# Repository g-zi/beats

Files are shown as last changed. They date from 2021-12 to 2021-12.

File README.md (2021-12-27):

# BEATS
## Beat Couter, MIDI controller and DMX light controller in one

A small box that is connected to the computer via USB and shows the beat as a clock and digits so that can be mixed in the beat. It can be used as a MIDI and DMX controller and can control a lighting system in the beat.

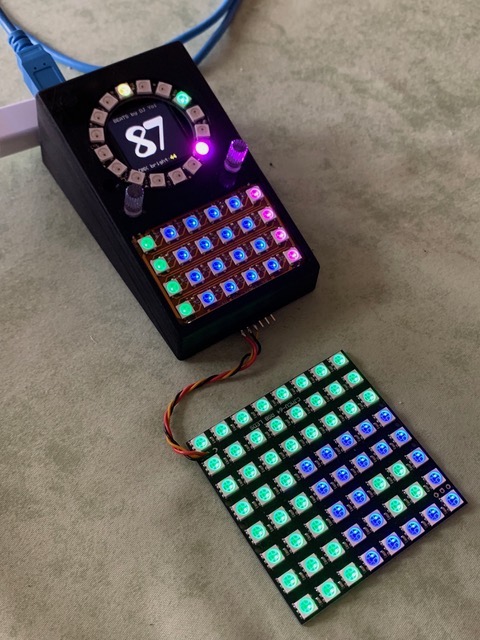
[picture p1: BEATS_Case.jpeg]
BEATS Case

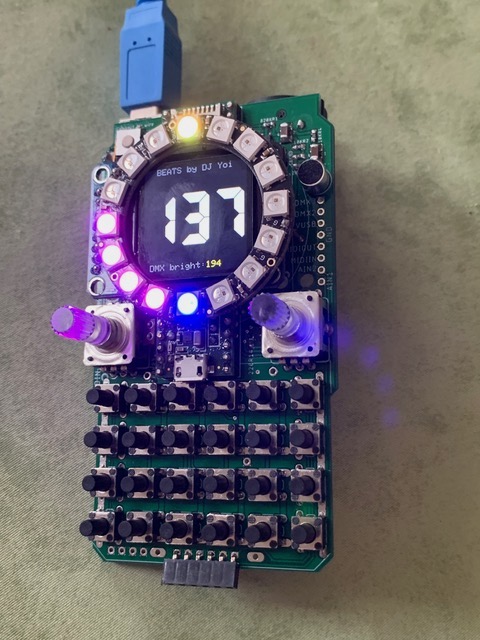
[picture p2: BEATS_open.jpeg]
BEATS open
 

The Beat Counter knows 3 operating modes:

- MIDI (drum pad, beat clock and metronome)
- Scanners (and moving heads with up to 8 scanners with 8 channels or 4 scanners with up to 16 channels)
- COB (Pixbar and Pattern)

Can operate with anything that sends/receives MIDI commands: Ableton Live, Serato, Traktor …

Beat length adjustable, inclined beats such as 9 are also adjustable.
The key matrix is pressure-sensitive and illuminated with RGB LEDs. A milky silicone pad is attached to the key matrix.
There are two illuminated encoders that are used to set the lighting system and can also send MIDI signals.
Reads and writes MIDI signals via USB and DIN socket.
Outputs DMX control signals for light control for COB bars, 8x8 COB arrays and scanners / moving heads. Up to 8 scanners / moving heads can be controlled at the same time.
SD card slot accessible from the rear.
The housing is designed with OpenSCAD and is printed with 3D printers (Form3 or FDM)
The current version uses a Teensy 3.6, the next version will have a Teensy 4.1 (600Mhz).
The board is two-sided and created with Eagle.

Here some videos: 
- Controlling scanners / moving heads: https://www.youtube.com/watch?v=9kyjajE7mRk
- Animation of the circuit board: https://www.youtube.com/watch?v=K_6d6vQXQpI 
- Inner workings with a few functions: https://www.youtube.com/watch?v=Ms0J2bLOR1w 
- 4 x Showtec Pixel Square 16 COB (old version): https://www.youtube.com/watch?v=BX3hZSje4Ws
- Also works with bars (old version): https://www.youtube.com/watch?v=ibh8aw3B2aw
- MIDI Beat Counter Setup and Menues Part 1: https://www.youtube.com/watch?v=dCm0thBqy6s
- MIDI Beat Counter Setup and Menues Part 2: https://www.youtube.com/watch?v=OodJnmjo3fk

In MIDI mode, the key matrix is used as pressure-sensitive pads for e.g. Ableton Live. All buttons send MIDI commands. The two encoders send MIDI commands for buttons and each can be switched between 3 settings. MIDI channel and address can be set.

The scanner mode is used to control up to 8 scanners or moving heads with 8 channels or 4 scanners with up to 16 channels. All settings such as pan, tilt, color, strobe etc. can be set individually for each scanner and up to 32 settings can be saved by now.

In movement mode there are 9 movement patterns such as Left-Right, Circle, Swing etc. which the scanner let move to the rhythm of the music. The movement path and speed can be selected, in beat in steps and free run mode.

The COB mode is for COB-LED walls, until now for a matrix of 8x8 COBs. A counting pattern can be set or programmed patterns can be send out. The patterns run to the beat of the music, foreground and background brightness can be adjusted. Lightbulbs are simulated, slowly decay.

The housing is designed to be as stable as possible. On the underside there are bars under the key matrix so that nothing can bend or break even with firm pressure. The two screws for the circuit board are in the immediate vicinity of the encoder, even here nothing can be broken by applying too much pressure to the encoder. An M8 nut will also be integrated into the housing on the underside so that the device can also be screwed on. The size of the Beat Counter is kept compact and can therefore be mounted within sight.

## Further development:

The USB host port can be used to connect external devices, keyboard, drum pads etc. (Korg, Akai) https://www.pjrc.com/wp-content/uploads/2020/05/teensy41_usbhost3.jpg https://forum.pjrc.com/teensy41_usbhost2.jpg

Explanation to DMX: https://en.wikipedia.org/wiki/DMX512#RJ-45_pinout

In the current device I am using a Teensy 3.6. I am developing a circuit board for the Teensy 4.1. Teensy 4.1: https://www.pjrc.com/store/teensy41.html

Instead of the MIDI-DIN socket, an RJ45 socket will be installed: Ethernet can be used to beat-link CDJs such as beat-link-trigger or for Art-Net

Art-Net: https://artisticlicence.com/WebSiteMaster/User%20Guides/art-net.pdf

Conversion of the pattern for the COB-LED walls to the SD card and writing the program for generating the pattern, then larger output than 8x8 are possible.

Teensy 4.1 can use S/PDIF and can be later used for sound analysis, Fourier transformation and as an effects device: https://en.wikipedia.org/wiki/S/PDIF

The displays are also available in round. This display can be exchanged 1: 1 (same driver ST7789): 250nits: http://www.panelook.com/TVT0128A-I-IPS-1-28-Inch-240x240-Round-TFT-LCD-Circular-Display-Module-For-VR-detail_71679.html 400nits: http://www.panelook.com/TVT0128C-I-IPS-1-28-Inch-240x240-Round-TFT-LCD-Circular-Display-Module-For-VR-detail_98507.html or as OLED with 400x400 resolution, but are quite expensive and probably too slow: https://www.ebay.de/itm/Real-AMOLED-Display-1-39-inch-400-400-Round-Circle-Circular-OLED-LCD-Module/192716558403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

An LED strip control can also be installed, the neopixels are already controlled like this: https://www.ebay.de/itm/WS2812B-LED-Streifen-Strip-5M-WS2812-RGB-Leiste-Licht-5050-SMD-Adressbaren-DC5V/222192610445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Ⓜ️m48DHbcLw8Ppkncw-fkDSGA

Something else interesting could easily be integrated: https://github.com/saikoLED/TeensyLED

If someone is interrested to build it, I still have some PCB's and can send for 10 Euros each plus shipping costs. For further questions send email to g.zi@gmx.de

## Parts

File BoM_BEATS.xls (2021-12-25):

Teensy Beat Counter |  | Bill of Material
Amount | Part | Value | Device | Package | Seller | Seller N° | Price € | Total | Remark
1 | Teensy | 3.6 | Teensy 3.6 | Teensy_3.6 | exp-tech.de | EXP-R05-965 | 30.39 | 30.39
1 | NEO16RING | 16 | Neopixel Ring 16 | Neo16ring3 | exp-tech.de | EXP-R15-225 | 10.65 | 10.65 | Reichelt: DEBO LED NP16
1 | WS_1.3"240X240 | 1.3" 240X240 | WS_1.3"240X240 | WS_1.3"240X240 | exp-tech.de | EXP-R63-227 | 10.06 | 10.06
1 | FSR | 44x44mm | interlink 406 | 44x44mm | exp-tech.de | EXP-R15-074 | 10.65 | 10.65
3 | NeoPixel RGB | RGB-LED | NeoPixel RGB LED | 5050 | exp-tech.de | EXP-R15-315 | 2.38 | 7.14 | 10 Pack
2 | RGB Encoder | ENC1 & ENC2 | RGB Encoder | ENCODER_LED_3_LONG | ebay.de albs-alltronic (http://www.reichelt.de/) | 1x/10x Encoder RGB LED | 4.00 | 8.00
1 | DMX | NC3FAH2 | NC3FAH2 | NC3FAH2 | thomann.de | Neutrik NC3 FAH1 | 1.09 | 1.09
1 | MIC | F6035AP | F6035AP | F6035AP | reichelt.de | EMY-63M/P | 0.95 | 0.95
1 | USB-B | USB-B-H | USB-B-H | USB-B-H | reichelt.de | RND 205-00858 | 0.25 | 0.25
1 | MAX3468 | MAX3468CSA | MAX3468CSA | SO08 | reichelt.de | SP 485 CNL | 0.77 | 0.77
2 | OPA344 | MCP6401 | LM 8261 | SOT23-5 | reichelt.de | MCP 6401T-E/OT | 0.30 | 0.60 | LM 8261 M5 | OPA 335 AIDBVT
3 | 4.7µF C1-C3 | 4.7µF | C-EUC1210 | C1210 | reichelt.de | X7R-G1206 4,7/50 | 0.20 | 0.60
16 | 220R R1-R16 | 220R | R-EU_R0603 | R0603 | reichelt.de | SMD-0603 220 | 0.03 | 0.48
1 | 2K2R1 | 2K2 | R-EU_R0603 | R0603 | reichelt.de | SMD-0603 2,2K | 0.03 | 0.03
6 | 10K R1-R6 | 10K | R-EU_R0603 | R0603 | reichelt.de | SMD-0603 10K | 0.03 | 0.18
3 | 100K R1-R3 | 100k | R-EU_R0603 | R0603 | reichelt.de | SMD-0603 100K | 0.03 | 0.09
1 | 820KR1 | 820K | R-EU_R0603 | R0603 | reichelt.de | SMD-0603 820K | 0.10 | 0.10
1 | Button | SMD_5.2MM | SMD_5.2MM | SMD_5.2MM | reichelt.de | OMR B3FS-1002P | 0.21 | 0.21
24 | Switch | 9.5mm | B3F-10XX | B3F-10XX | reichelt.de | TASTER 3301B | 0.15 | 3.60
1 | Buchsenleiste | 20 pol | Buchsenleiste | Buchsenleiste | reichelt.de | BL 1X20W 2,54 | 0.80 | 0.80
1 | Schraube | M3 x 18mm | Schraube | Senkkopf | minischrauben.com | 10642-2-318 | 5.01 | 0.05 | https://minischrauben.com/senkschrauben-m-3-x-18-ve100--30680.html
1 | Schraube | M3 x 15mm | Schraube | Zylinderkopf | minischrauben.com | 912-2-314 | 3.27 | 0.03 | https://minischrauben.com/zylinderschrauben-m-3-x-14-ve100--13029.html
2 | Schraube | M2 x 12mm | Schraube | Torx | minischrauben.com | 965tx-2-212-50 | 2.12 | 0.0848 | https://minischrauben.com/senkschrauben-m-2-x-12-ve50--36215.html
2 | Schraube | M2 x 20mm | Schraube | Torx | minischrauben.com | 965tx-2-220-50 | 2.12 | 0.0848 | https://minischrauben.com/senkschrauben-m-2-x-20-ve50--36217.html
2 | Schraube | M3 x 10mm | Schraube | Torx | minischrauben.com | 965tx-2-38-50 | 2.03 | 0.0812 | https://minischrauben.com/senkschrauben-m-3-x-8-kp--50-stueck--42896.html
1 | Mutter | M3 | Mutter | M3 | minischrauben.com | 934-4-2-100 | 2.45 | 0.098 | https://minischrauben.com/sechskantmuttern-m-2-ve100--1997.html
2 | Beilagscheibe | M3 Isolierend | Beilagscheibe | M3 | pegnitz-schrauben.de | 9021903 | 0.05 | 0.10 | https://www.pegnitz-schrauben.de/U-Scheiben-DIN-9021-Polyamid-32mm-fuer-M3 | https://www.ebay.de/itm/222409316877
1 | Foil | 55x37mm | Foil | Foil | DJ_Yoi | MBC 3.6 Foil | 1.00 | 1.00
1 | 6x4 PCB | 6x4 PCB | 6x4 PCB | 6x4 PCB | DJ_Yoi | MBC 3.6 6x4 PCB | 10.00 | 10.00
1 | PCB | PCB | PCB | PCB | DJ_Yoi | MBC 3.6 PCB | 10.00 | 10.00
1 | Case | Case | Case | Case | DJ_Yoi | MBC 3.6 Case | 10.00 | 10.00
 |  |  |  |  |  |  |  | 118.17 | €

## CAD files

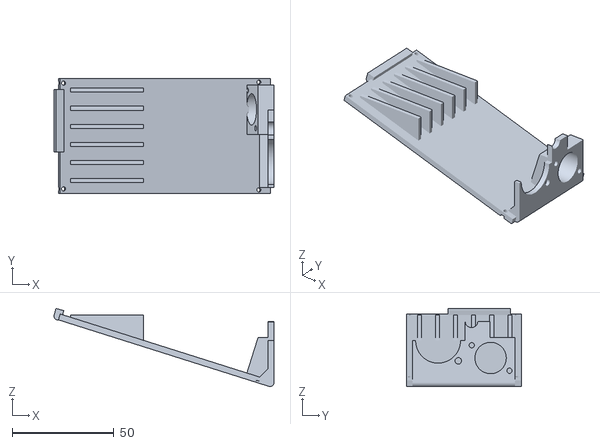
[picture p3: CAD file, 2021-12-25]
BEATS_bottom.stl
107.9 x 56.2 x 38.3

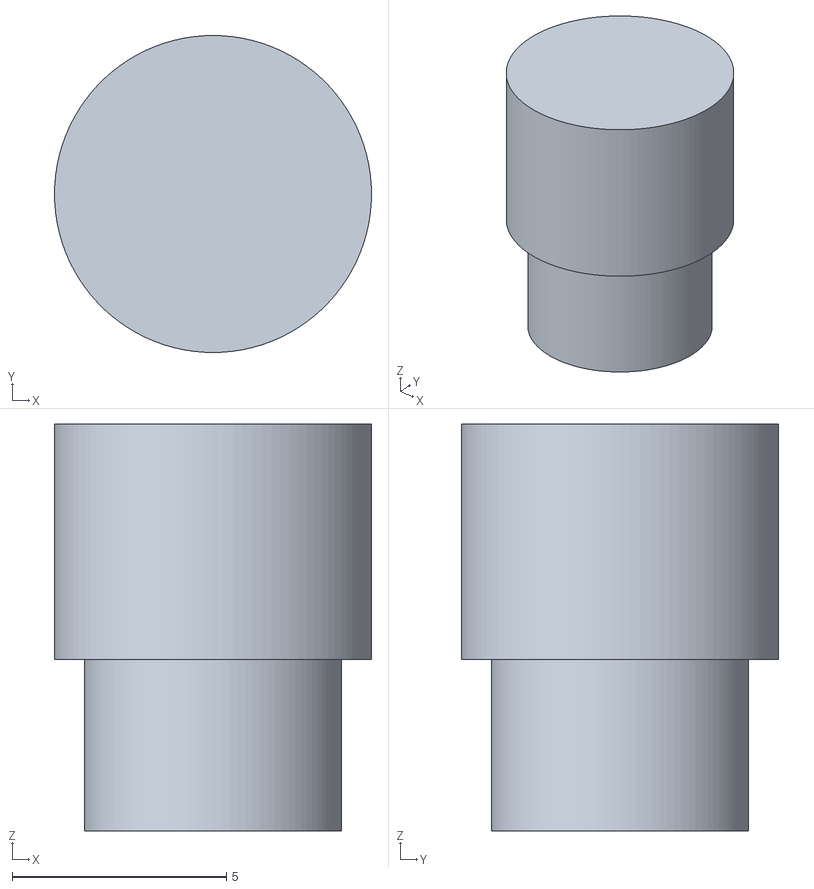
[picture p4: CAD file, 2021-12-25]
BEATS_Shift.stl
7.40 x 7.40 x 9.50

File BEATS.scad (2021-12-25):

// MIDI Beat Counter 
// Case and assemble
// Author Georg Zieger
// g.zi@gmx.de
// 
// neopixel ring von 1820 nach 1850 um 5 mil (0.127mm) nach unten geschoben


_W = 55.88;   // PCB width
_L = 99.949;  // PCB lenght
_gap = 0.15;  // gap between PCB anc case, will decrease wall thickness
_Hb = 47;     // case height back
_Hf = 14.4;   // case height front
_sp = 2;      // sphere radius
_wt = 2-_sp;  // wall thickness
_top = 3.2;   // top wall thickness
_btn = 3;     // bottom wall thickness
_pcbt = 1.6;  // PCB thickness
_dispt = 9.2; // total display height over PCB
_disph = 7.6; // display height over PCB
_sc = 0.4;    // screen thickness foliage over rgb keys
_kh = 9.5;    // key height over PCB
_shift = 0.3; // space for shift switch 
$fn = 100;    // circle fragments 

/*
rotate([180,0,90]) color("DimGray") case();
rotate([180,0,90]) pcb(_hole);
rotate([180,0,90]) usb();
rotate([180,0,90]) audio();
rotate([180,0,90]) dmx();
*/

rotate([0,0,90]) color("DimGray") case();
//rotate([0,0,90]) display();
//rotate([180,0,90]) color("DimGray") bottom();
//rotate([162.45 ,0 ,90]) translate([0,0,-17.1764]) color("DimGray") bottom(); 
//rotate([0,0,90]) color("DimGray") shift();
//rotate([0,0,90]) pcb();
//rotate([0,0,90]) flex_led();
//rotate([0,0,90]) bolt_case();

//rotate([180,0,90]) inner(); // activate this for animation 
_cutx  = 50;    // cut case in x direction, no cut = 0, range 0-116
_cuty  = 0;   // cut case in y direction, no cut = 0, range 0-206
_hole = 0 ;      // view holes in PCB
_explode = 0; // height of explosion (10 shows text), values higher 100 for animation (300)
                // for animation activate View-Animate (FPS:5, Steps:200, _hole=0)

                // create GIF with brew install ImageMagick
                // convert *.png screens.gif

_t0 = 0     ;
_t1 = 0.04  ;
_t2 = 0.08  ;
_t3 = 0.12  ;
_t4 = 0.16  ;
_t5 = 0.2   ;
_t6 = 0.24  ;
_t7 = 0.28  ;
_t8 = 0.32  ;
_t9 = 0.36  ;
_t10 = 0.4  ;
_t11 = 0.44 ;
_t12 = 0.48 ;
_t13 = 0.52 ;
_t14 = 0.56 ;
_t15 = 0.6  ;
_t16 = 0.64 ;
_t17 = 0.68 ;
_t18 = 0.72 ;
_t19 = 0.76 ;
_t20 = 0.8  ;
_t21 = 0.84 ;
_t22 = 0.88 ;
_t23 = 0.92 ;
_t24 = 0.96 ;
_t25 = 1    ;

module inner() {
// color("red") 

if(_explode>=100) {
  translate([0,0,0]) pcb(_hole);
  if($t>_t0 && $t<=_t1)   translate([0,0,-($t-_t1)*_explode*2]) audio();
  else if($t>_t1)                                               audio();

  if($t>_t1 && $t<=_t2)     translate([0,0, ($t-_t2)*_explode]) usb_wire();
  else if($t>_t2)                                               usb_wire();
  if($t>_t1 && $t<=_t2)     translate([0,0, ($t-_t2)*_explode]) mic();
  else if($t>_t2)                                               mic();

  if($t>_t2 && $t<=_t3)     translate([0,0, ($t-_t3)*_explode]) teensy();
  else if($t>_t3)                                               teensy();
  if($t>_t3 && $t<=_t4)     translate([0,0, ($t-_t4)*_explode]) encoder();
  else if($t>_t4)                                               encoder();
  if($t>_t4 && $t<=_t5)     translate([0,0, ($t-_t5)*_explode]) keyboard();
  else if($t>_t5)                                               keyboard();
  if($t>_t5 && $t<=_t6)     translate([0,0, ($t-_t6)*_explode]) connect();
  else if($t>_t6)                                               connect();
  if($t>_t6 && $t<=_t7) translate([0,0,-($t-_t7)*_explode*2.5]) usb();
  else if($t>_t7)                                               usb();
  if($t>_t7 && $t<=_t8)     translate([0,0,-($t-_t8)*_explode]) dmx();
  else if($t>_t8)                                               dmx();
  if($t>_t8 && $t<=_t9)     translate([0,0, ($t-_t9)*_explode]) display();
  else if($t>_t9)                                               display();
  if($t>_t9 && $t<=_t10)   translate([0,0, ($t-_t10)*_explode]) flex_wire();
  else if($t>_t10)                                              flex_wire();
  if($t>_t10 && $t<=_t11)  translate([0,0, ($t-_t11)*_explode]) fsr();
  else if($t>_t11)                                              fsr();
  if($t>_t11 && $t<=_t12)  translate([0,0, ($t-_t12)*_explode]) neopixel_data();
  else if($t>_t12)                                              neopixel_data();
  if($t>_t12 && $t<=_t13)  translate([0,0, ($t-_t13)*_explode]) flex_led();
  else if($t>_t13)                                              flex_led();
  if($t>_t13 && $t<=_t14)  translate([0,0, ($t-_t14)*_explode]) neopixel_wire();
  else if($t>_t14)                                              neopixel_wire();
  if($t>_t14 && $t<=_t15)  translate([0,0, ($t-_t15)*_explode]) neopixel_ring();
  else if($t>_t15)                                              neopixel_ring();

  if($t>_t15 && $t<=_t16) translate([0,0, ($t-_t16)*_explode*3]) color("DimGray") case();
  else if($t>_t16)                                               color("DimGray") case();
  if($t>_t15 && $t<=_t16) translate([0,0, ($t-_t16)*_explode*3]) folio();
  else if($t>_t16)                                               folio();
  if($t>_t15 && $t<=_t16) translate([0,0, ($t-_t16)*_explode*1]) shift();
  else if($t>_t16)                                               shift();

  if($t>_t16 && $t<=_t17) translate([0,0, ($t-_t17)*_explode]*2) nut_top();
  else if($t>_t17)                                               nut_top();

  if($t>_t17 && $t<=_t18) translate([0,-($t-_t18)*_explode]*2,0) nut_dmx();
  else if($t>_t18)                                               nut_dmx();

  if($t>_t18 && $t<=_t19) translate([0,0,-($t-_t19)*_explode*2.7]) washer_top();
  else if($t>_t18)                                                 washer_top();
  if($t>_t18 && $t<=_t19) translate([0,0,-($t-_t19)*_explode*3])   bolt_top();
  else if($t>_t18)                                                 bolt_top();
  if($t>_t18 && $t<=_t19) translate([0,0,-($t-_t19)*_explode*1])   washer_bottom();
  else if($t>_t18)                                                 washer_bottom();
  if($t>_t18 && $t<=_t19) translate([0,0,-($t-_t19)*_explode*3])   nut_bottom();
  else if($t>_t18)                                                 nut_bottom();

  if($t>_t19 && $t<=_t20)     translate([0,0,-($t-_t20)*_explode]) color("DimGray") bottom();
  else if($t>_t20)                                                 color("DimGray") bottom();

  if($t>_t20 && $t<=_t21)     translate([0,-($t-_t21)*_explode*1.5, 0]) MIDI_DIN_conn();
  else if($t>_t21)                                                      MIDI_DIN_conn();
  if($t>_t21 && $t<=_t22)     translate([0,-($t-_t22)*_explode*3.5, 0]) nut_MIDI();
  else if($t>_t22)                                                      nut_MIDI();

  if($t>_t23 && $t<=_t24)  bolt_case(-($t-_t24)*_explode*2);
  else if($t>_t24)                           bolt_case(0);

  }

else {
  translate([0,0,0]) pcb(_hole);
  translate([0,0,-_explode*0.8]) usb_wire();
  translate([0,0,-_explode*1.6]) teensy();
  translate([0,0,-_explode*1]) mic();
  translate([0,0,-_explode*2]) keyboard();
  translate([0,0,-_explode*1]) connect();
  translate([0,0, _explode*1]) usb();
  translate([0,0, _explode*1]) audio();
  translate([0,0, _explode*1]) dmx();
  translate([0,0,-_explode*2]) encoder();
  translate([0,0,-_explode*3]) display();
  translate([0,0,-_explode*3]) flex_wire();
  translate([0,0,-_explode*4]) fsr();
  translate([0,0,-_explode*5]) flex_led();
  translate([0,0,-_explode*5]) neopixel_data();
  translate([0,0,-_explode*5]) neopixel_wire();
  translate([0,0,-_explode*6]) neopixel_ring();
  translate([0,0,-_explode*10.5]) nut_top();
  translate([0,0, _explode*1.1]) washer_top();
  translate([0,0, _explode*2 ]) bolt_top();
  translate([0,0, _explode*2.2]) nut_bottom();
  translate([0,0, _explode*0.6]) washer_bottom();
  translate([0,0,-_explode*8]) color("DimGray") case();
  translate([0,0,-_explode*2]) shift();
  translate([0,_explode*1.5,-_explode*8]) nut_dmx();
  translate([0,-_explode*0.685, _explode*2.5]) color("DimGray") bottom();
  translate([0, _explode*1.5, _explode*2.5]) MIDI_DIN_conn();
  translate([0, _explode*3.5, _explode*2.5]) nut_MIDI();
  bolt_case(_explode*5);
  translate([0,0,-_explode*8]) folio();
  if(_explode==10) color("red") doku(4);
}}



module case() {

//      translate([ _W/2+10.1, -6.1/2 + 2.413, 12.3]) rotate([15.5,0,0]) cube([ 4.7, 7, 2.6],center=true);
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

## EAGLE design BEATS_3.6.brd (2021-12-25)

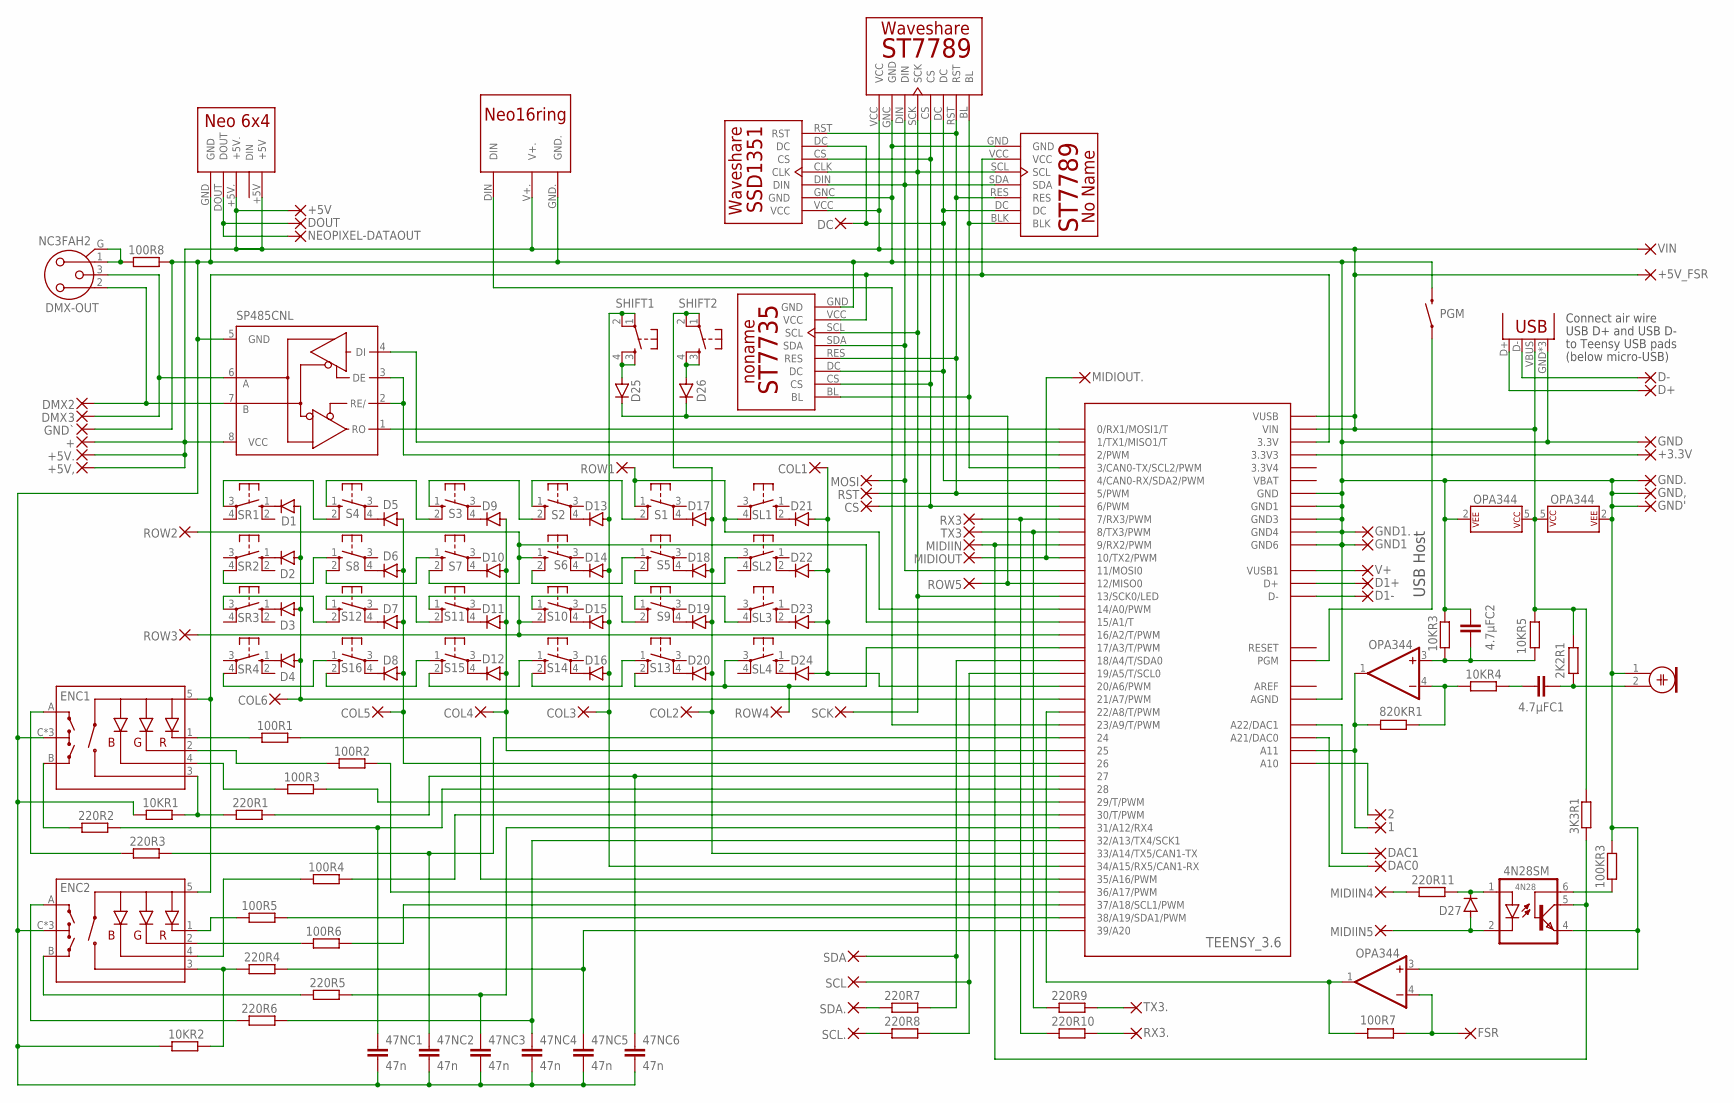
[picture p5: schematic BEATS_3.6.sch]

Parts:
1, 2, 3: 1,6/0,8
2K2R1: 2K2; R0603
3K3R1: 3k3; R0603
4.7µFC1, 4.7µFC2: 4.7µF; C1210
4N28: 4N28SM; DIL6-SMD
10KR1, 10KR2: 10k; R0603
10KR3, 10KR4, 10KR5: 10K; R0603
47NC1, 47NC2, 47NC3, 47NC4, 47NC5, 47NC6: 47n; C0603
100KR3: 100k; R0603
100R1, 100R2, 100R3, 100R4, 100R5, 100R6, 100R8, 220R1, 220R2, 220R3, 220R4, 220R5, 220R6, 220R7, 220R8, 220R9, 220R10, 220R11: 220R; R0603
100R7: 100R; R0603
820KR1: 820K; R0603
+, +5V, +5V,, +5V., +5V_FSR: 1,6/0,8
+3.3V: +3.3v; 1,6/0,8
COL1, COL2, COL3, COL4, COL5, COL6: 1,6/0,8
CS: 1,6/0,8
D1, D2, D3, D4, D5, D6, D7, D8, D9, D10, D11, D12, D13, D14, D15, D16, D17, D18, D19, D20, D21, D22, D23, D24, D25, D26, D27: 1N4148DO34-5; DO34-5
D1+, D1-: 1,6/0,8
D+: 1,6/0,8
D-: 1,6/0,8
DAC0, DAC1: 1,6/0,8
DC: 1,6/0,8
DMX2: 1,6/0,8
DMX-OUT: NC3FAH2
DOUT: 1,6/0,8
ENC1, ENC2: ENCODER-RGB-SWITCHENCODER_LED_3_LONG; ENCODER_LED_3_LONG
FSR: 1,6/0,8
GND, GND1, GND1., GND.: 1,6/0,8
GND': 1,6/0,8
GND,: 1,6/0,8
GND`: 1,6/0,8
MIC: ELECTRET_MICROPHON-F6035AP; F6035AP
MIDIIN, MIDIIN4, MIDIIN5: 1,6/0,8
MIDIOUT, MIDIOUT.: 1,6/0,8
MOSI: 1,6/0,8
NEOPIXEL-DATAOUT: 1,6/0,8
OPA348,, OPA348.: OPA344; SOT23-5
PGM: MOMENTARY-SWITCH-SPST-SMD-4.6X2.8MM; TACTILE_SWITCH_SMD_4.6X2.8MM
ROW1, ROW2, ROW3, ROW4, ROW5: 1,6/0,8
RST: 1,6/0,8
RX3, RX3.: 1,6/0,8
S1, S2, S3, S4, S5, S6, S7, S8, S9, S10, S11, S12, S13, S14, S15, S16: 10-XXLONG; B3F-10XX
SCK: 1,6/0,8
SCL, SCL.: 1,6/0,8
SDA, SDA.: 1,6/0,8
SHIFT1, SHIFT2: MOMENTARY-SWITCH-SPST-2-SMD-5.2MM; TACTILE_SWITCH_SMD_5.2MM
SL1, SL2, SL3, SL4: 10-XXIN; B3F-10XX1
SP485CNL: MAX3468CSA; SO08
SR1, SR2, SR3, SR4: 10-XXIN; B3F-10XX1
TEENSY_3.6: TEENSY_3.6_ALL_PINS
TX3, TX3.: 1,6/0,8
U$1: WS_1.3"240X240_3.3V
U$2: WS_1.5"128X128_OLEDOLED; WS_1.5"128X128_OLED
U$3: WS_1.3"240X240ROUND; WS_1.3"240X240_ROUND
U$4: NEO16RING
U$5: WS_1.44"128X128WS_1.44"128X128; WS_1.44"128X128
U$7: NEOPIXEL_6X4
USB-B: USB-B-H
V+: 1,6/0,8
VIN: +3.3v; 1,6/0,8

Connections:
3.3V: +3.3V.1, TEENSY_3.6.3.3V3
3.3V4: TEENSY_3.6.3.3V4
3V3: ENC1.5 (+), ENC2.5 (+), TEENSY_3.6.3.3V, U$1.VCC, U$5.VCC
AIN1: 1.1, 820KR1.1, OPA348..1 (OUT), TEENSY_3.6.A11
AIN2: 2.1, TEENSY_3.6.A10
AREF: TEENSY_3.6.AREF
BL: TEENSY_3.6.3 (3/CAN0-TX/SCL2/PWM), U$1.BLK, U$3.BL, U$5.BL
COL1: COL1.1, D21.A, D22.A, D23.A, D24.A, TEENSY_3.6.20/A6 (20/A6/PWM)
COL2: COL2.1, D17.A, D18.A, D19.A, D20.A, SHIFT2.1, SHIFT2.2, TEENSY_3.6.33/A14 (33/A14/TX5/CAN1-TX)
COL3: COL3.1, D13.A, D14.A, D15.A, D16.A, SHIFT1.1, SHIFT1.2, TEENSY_3.6.34/A15 (34/A15/RX5/CAN1-RX)
COL4: COL4.1, D9.A, D10.A, D11.A, D12.A, TEENSY_3.6.25
COL5: COL5.1, D5.A, D6.A, D7.A, D8.A, TEENSY_3.6.26
COL6: COL6.1, D1.A, D2.A, D3.A, D4.A, TEENSY_3.6.21/A7 (21/A7/PWM)
CS: CS.1, TEENSY_3.6.6 (6/PWM), U$2.CS, U$3.CS, U$5.CS
D1+: D1+.1, TEENSY_3.6.D+
D1-: D1-.1, TEENSY_3.6.D-
D+: D+.1, USB-B.D+
D-: D-.1, USB-B.D-
DAC0: DAC0.1, TEENSY_3.6.A21 (A21/DAC0)
DAC1: DAC1.1, TEENSY_3.6.A22 (A22/DAC1)
DC: DC.1, TEENSY_3.6.4 (4/CAN0-RX/SDA2/PWM), U$1.DC, U$2.DC, U$3.DC, U$5.DC
DIN: MOSI.1, TEENSY_3.6.11 (11/MOSI0), U$1.SDA, U$2.DIN, U$3.DIN, U$5.SDA
DMXEN: SP485CNL.2 (RE/), SP485CNL.3 (DE), TEENSY_3.6.2 (2/PWM)
DMXIN: SP485CNL.1 (RO), TEENSY_3.6.0 (0/RX1/MOSI1/T)
DMXIN.: DMX2.1, DMX-OUT.2 (1), SP485CNL.7 (B)
DMXOUT: SP485CNL.4 (DI), TEENSY_3.6.1 (1/TX1/MISO1/T)
DMXOUT.: 3.1, DMX-OUT.3, SP485CNL.6 (A)
DOUT: DOUT.1, NEOPIXEL-DATAOUT.1, U$7.DOUT
ENC1A: 47NC2.1, 220R3.2, TEENSY_3.6.24
ENC1A.: 220R3.1, ENC1.A
ENC1B: 47NC1.1, 220R2.2, TEENSY_3.6.28
ENC1B.: 220R2.1, ENC1.B
ENC1BL: 100R3.2, TEENSY_3.6.29 (29/T/PWM)
ENC1BL.: 100R3.1, ENC1.4 (-B)
ENC1GN: 100R2.2, TEENSY_3.6.36/A17 (36/A17/PWM)
ENC1GN.: 100R2.1, ENC1.2 (-G)
ENC1RT: 100R1.2, TEENSY_3.6.35/A16 (35/A16/PWM)
ENC1RT.: 100R1.1, ENC1.1 (-R)
ENC1SW: 47NC6.1, 220R1.2, TEENSY_3.6.27
ENC1SW.: 10KR1.2, 220R1.1, ENC1.3 (SW)
ENC2A: 47NC4.1, 220R6.2, TEENSY_3.6.32/A13 (32/A13/TX4/SCK1)
ENC2A.: 220R6.1, ENC2.A
ENC2B: 47NC3.1, 220R5.2, TEENSY_3.6.31/A12 (31/A12/RX4)
ENC2B.: 220R5.1, ENC2.B
ENC2BL: 100R4.2, TEENSY_3.6.30 (30/T/PWM)
ENC2BL.: 100R4.1, ENC2.4 (-B)
ENC2GN: 100R6.2, TEENSY_3.6.37/A18 (37/A18/SCL1/PWM)
ENC2GN.: 100R6.1, ENC2.2 (-G)
ENC2RT: 100R5.2, TEENSY_3.6.38/A19 (38/A19/SDA1/PWM)
ENC2RT.: 100R5.1, ENC2.1 (-R)
ENC2SW: 47NC5.1, 220R4.2, TEENSY_3.6.39/A20
ENC2SW.: 10KR2.2, 220R4.1, ENC2.3 (SW)
FSR: 100R7.1, OPA348,.1 (OUT), TEENSY_3.6.22/A8 (22/A8/T/PWM)
GND.: 4.7µFC2.1, 4N28.4 (EMI), 10KR1.1, 10KR2.1, 10KR3.2, 47NC1.2, 47NC2.2, 47NC3.2, 47NC4.2, 47NC5.2, 47NC6.2, 100KR3.2, 100R8.2, ENC1.C, ENC1.M1 (C), ENC1.M2 (C), ENC2.C, ENC2.M1 (C), ENC2.M2 (C), GND.1, GND1.1, GND1..1, GND'.1, GND,.1, GND..1, GND`.1, MIC.1, OPA348,.2 (P$V-), OPA348,.3 (+IN), OPA348..2 (P$V-), PGM.3 (2), PGM.4 (2), SP485CNL.5 (GND), TEENSY_3.6.AGND, TEENSY_3.6.GND, TEENSY_3.6.GND1, TEENSY_3.6.GND3, TEENSY_3.6.GND4, TEENSY_3.6.GND6, U$1.GND, U$2.GNC (GND), U$3.GNC (GND), U$4.GND., U$5.GND, U$7.GND, USB-B.GND, USB-B.P$1 (GND), USB-B.P$2 (GND)
MIC: 2K2R1.1, 4.7µFC1.2, MIC.2
MIDIIN: 3K3R1.2, 4N28.5 (COL), MIDIIN.1, TEENSY_3.6.9 (9/RX2/PWM)
MIDIIN.: 4N28.2 (C), D27.A, MIDIIN5.1
MIDIINGND: 4N28.1 (A), 220R11.2, D27.C
MIDIOUT: MIDIOUT.1, MIDIOUT..1, TEENSY_3.6.10 (10/TX2/PWM)
MISO: D25.C, D26.C, ROW5.1, TEENSY_3.6.12 (12/MISO0)
unnamed: 100R8.1, DMX-OUT.1 (2), DMX-OUT.G
unnamed: D1.C, SR1.1 (S)
unnamed: D2.C, SR2.1 (S)
unnamed: D3.C, SR3.1 (S)
unnamed: 100R7.2, FSR.1, OPA348,.4 (-IN)
unnamed: D4.C, SR4.1 (S)
unnamed: D5.C, S4.4 (P1)
unnamed: D6.C, S8.4 (P1)
unnamed: D7.C, S12.4 (P1)
unnamed: D8.C, S16.4 (P1)
unnamed: D9.C, S3.4 (P1)
unnamed: D10.C, S7.4 (P1)
unnamed: D11.C, S11.4 (P1)
unnamed: D12.C, S15.4 (P1)
unnamed: D13.C, S2.4 (P1)
unnamed: D14.C, S6.4 (P1)
unnamed: D15.C, S10.4 (P1)
unnamed: D16.C, S14.4 (P1)
unnamed: D17.C, S1.4 (P1)
unnamed: D18.C, S5.4 (P1)
unnamed: D19.C, S9.4 (P1)
unnamed: D20.C, S13.4 (P1)
unnamed: D21.C, SL1.2 (S1)
unnamed: D22.C, SL2.2 (S1)
unnamed: D23.C, SL3.2 (S1)
unnamed: D24.C, SL4.2 (S1)
unnamed: 4N28.6 (BAS), 100KR3.1
unnamed: 220R11.1, MIDIIN4.1
unnamed: D26.A, SHIFT2.3, SHIFT2.4
unnamed: D25.A, SHIFT1.3, SHIFT1.4
unnamed: 10KR4.1, 820KR1.2, OPA348..4 (-IN)
unnamed: 4.7µFC1.1, 10KR4.2
unnamed: 4.7µFC2.2, 10KR3.1, 10KR5.1, OPA348..3 (+IN)
NEO: TEENSY_3.6.23/A9 (23/A9/T/PWM), U$4.DIN
PGM: PGM.1, PGM.2 (1), TEENSY_3.6.PGM
ROW1: ROW1.1, S1.1 (S), SL1.4 (P1), TEENSY_3.6.14/A0 (14/A0/PWM)
ROW1': S3.2 (S1), S4.1 (S)
ROW1,: S2.2 (S1), S3.1 (S)
ROW1.: S1.2 (S1), S2.1 (S)
ROW1`: S4.2 (S1), SR1.3
ROW2: S5.2 (S1), SL2.3
ROW2': S7.1 (S), S8.2 (S1)
ROW2,: ROW2.1, S6.1 (S), S7.2 (S1), TEENSY_3.6.15/A1 (15/A1/T)
ROW2.: S5.1 (S), S6.2 (S1)
ROW2`: S8.1 (S), SR2.4 (P1)
ROW3: S9.1 (S), SL3.4 (P1)
ROW3': S11.2 (S1), S12.1 (S)
ROW3,: ROW3.1, S10.2 (S1), S11.1 (S), TEENSY_3.6.16/A2 (16/A2/T/PWM)
ROW3.: S9.2 (S1), S10.1 (S)
ROW3`: S12.2 (S1), SR3.3
ROW4: ROW4.1, S13.2 (S1), SL4.3, TEENSY_3.6.17/A3 (17/A3/T/PWM)
ROW4': S15.1 (S), S16.2 (S1)
ROW4,: S14.1 (S), S15.2 (S1)
ROW4.: S13.1 (S), S14.2 (S1)
ROW4`: S16.1 (S), SR4.4 (P1)
RST: RST.1, TEENSY_3.6.5 (5/PWM), U$1.RES, U$2.RST, U$3.RST, U$5.RES
RX3: 220R10.1, RX3.1, TEENSY_3.6.7 (7/RX3/PWM)
RX3.: 220R10.2, RX3..1
SCK: SCK.1, TEENSY_3.6.13 (13/SCK0/LED), U$1.SCL, U$2.CLK, U$3.SCK, U$5.SCL
SCL: 220R8.2, SCL.1, TEENSY_3.6.19/A5 (19/A5/T/SCL0)
SCL.: 220R8.1, SCL..1
SDA: 220R7.2, SDA.1, TEENSY_3.6.18/A4 (18/A4/T/SDA0)
SDA.: 220R7.1, SDA..1
TX3: 220R9.1, TEENSY_3.6.8 (8/TX3/PWM), TX3.1
TX3.: 220R9.2, TX3..1
V1: TEENSY_3.6.VUSB1, V+.1
VBAT: TEENSY_3.6.VBAT
VUSB: 2K2R1.2, 3K3R1.1, 10KR5.2, +.1, +5V.1, +5V,.1, +5V..1, +5V_FSR.1, OPA348,.5 (P$V+), OPA348..5 (P$V+), SP485CNL.8 (VCC), TEENSY_3.6.VIN, TEENSY_3.6.VUSB, U$2.VCC, U$3.VCC, U$4.V+., U$7.+5V, U$7.+5V., USB-B.VBUS, VIN.1

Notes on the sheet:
USB Host
USB D+ and USB D-
Connect air wire
to Teensy USB pads
(below micro-USB)
DMX

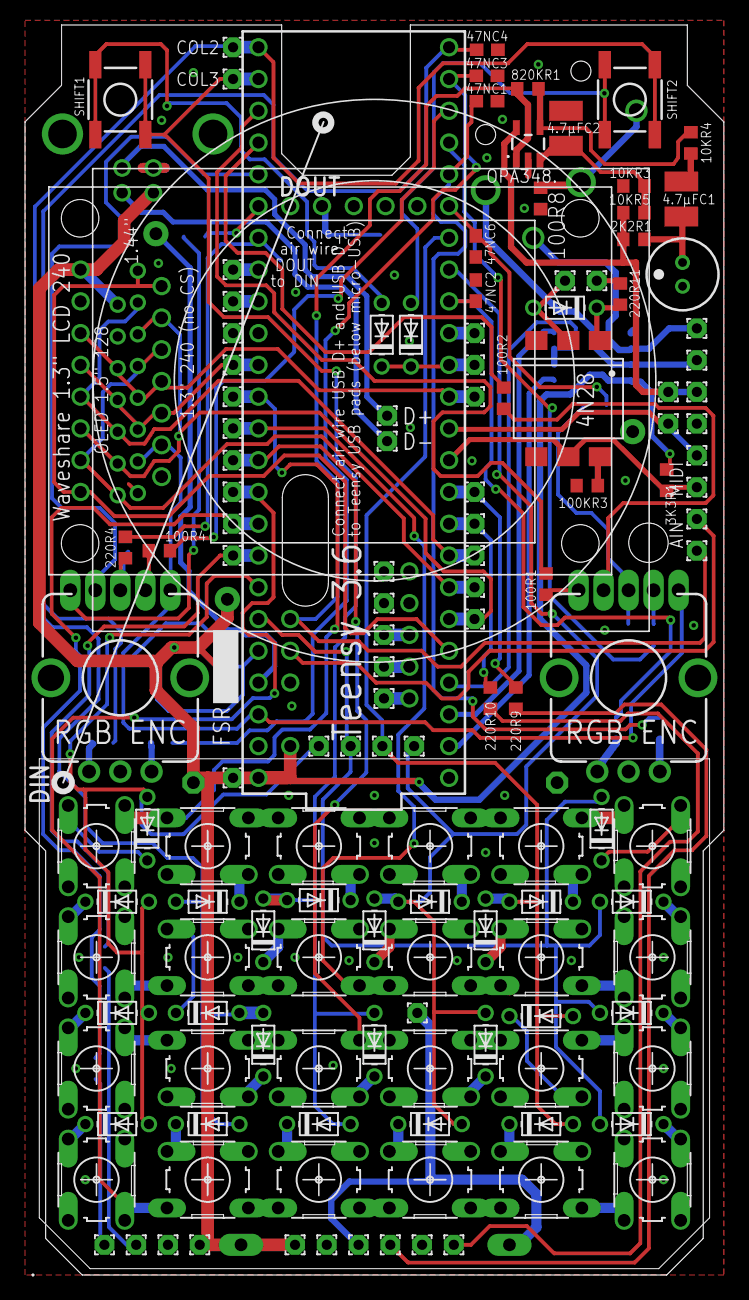
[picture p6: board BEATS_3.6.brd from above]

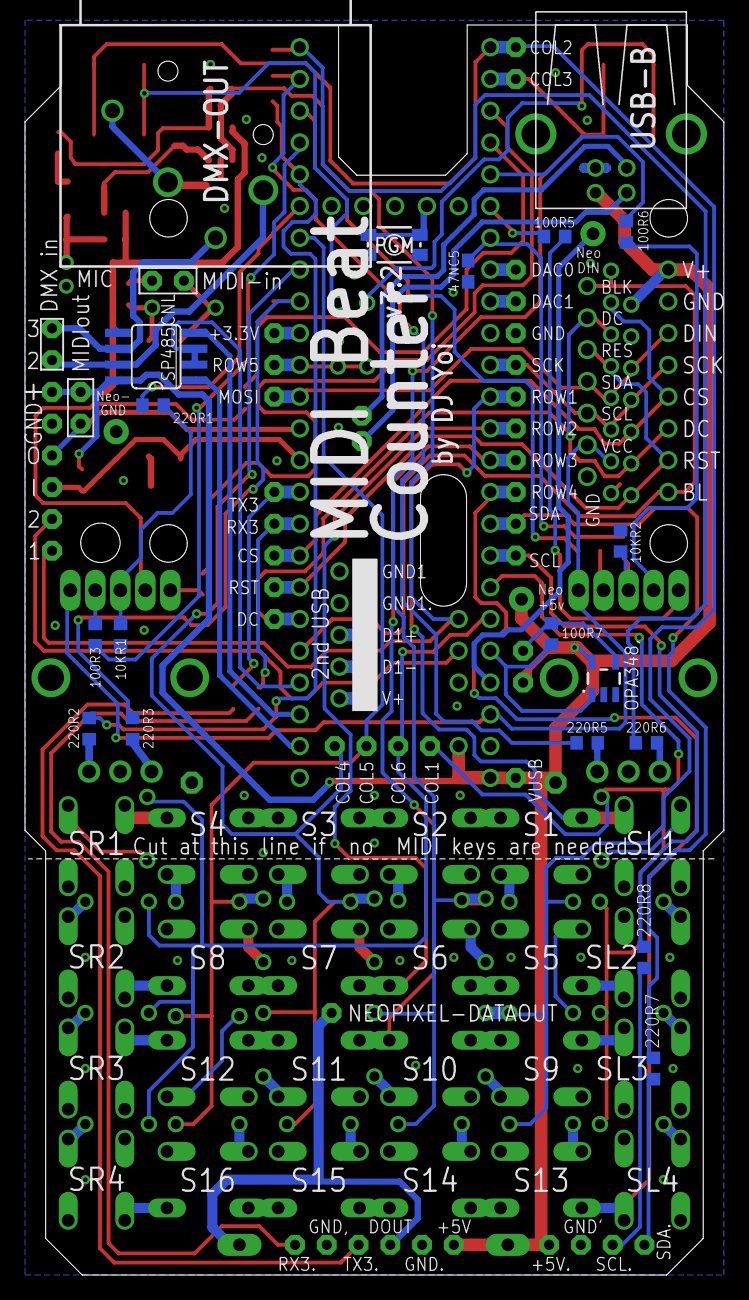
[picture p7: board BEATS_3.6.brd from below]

Board: 2 copper layers, 55.9 x 99.9 mm, 163 parts (19 on the bottom side), 125 nets.

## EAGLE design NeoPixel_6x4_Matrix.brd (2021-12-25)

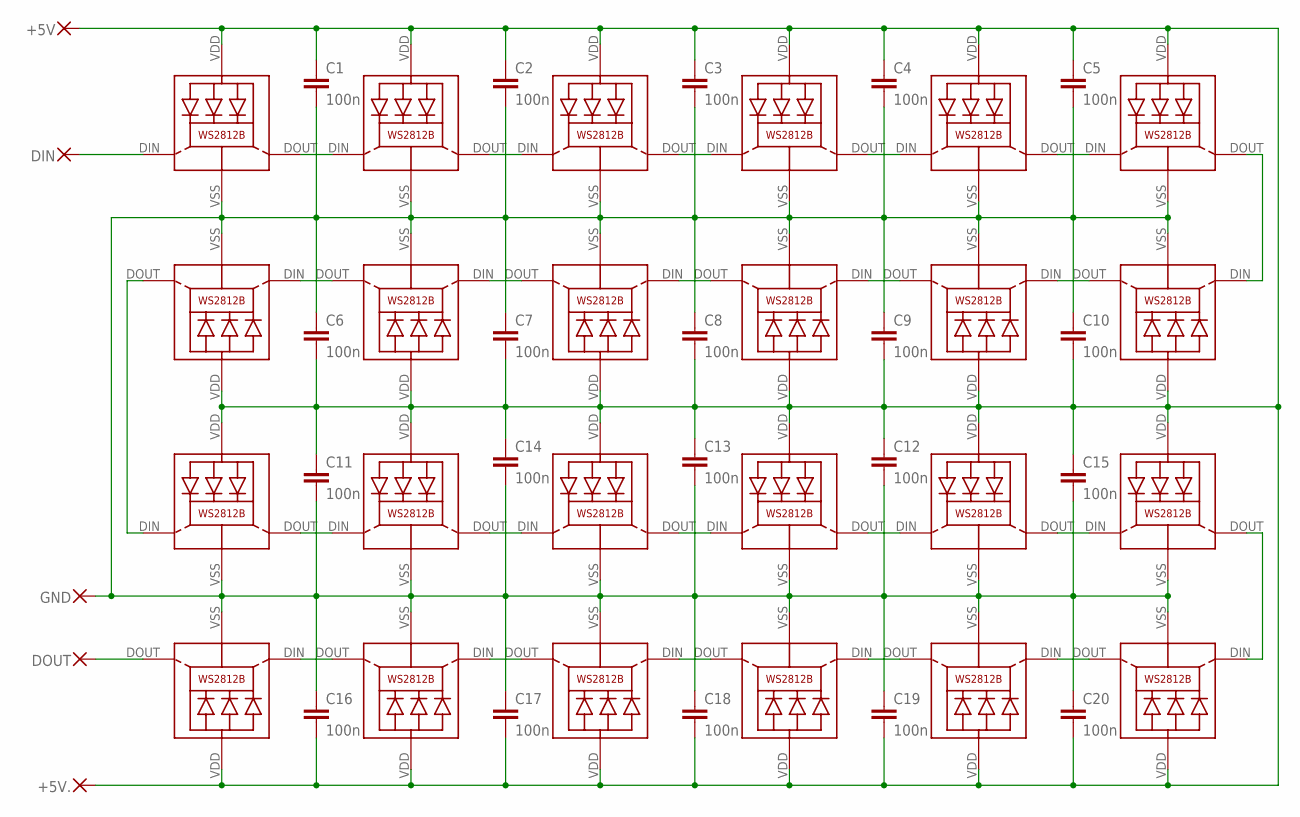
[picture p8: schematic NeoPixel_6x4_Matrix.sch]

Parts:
+5V, +5V.: 1,6/0,8
C1, C2, C3, C4, C5, C6, C7, C8, C9, C10, C11, C12, C13, C14, C15, C16, C17, C18, C19, C20: 100n; C0603
DIN: 1,6/0,8
DOUT: 1,6/0,8
GND: 1,6/0,8
LED1, LED2, LED3, LED4, LED5, LED6, LED7, LED8, LED9, LED10, LED11, LED12, LED13, LED14, LED15, LED16, LED17, LED18, LED19, LED20, LED21, LED22, LED23, LED24: WS2812B

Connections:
1-2: LED2.DOUT (DO), LED3.DIN (DI)
2-3: LED3.DOUT (DO), LED4.DIN (DI)
3-4: LED4.DOUT (DO), LED5.DIN (DI)
4-5: LED6.DOUT (DO), LED7.DIN (DI)
5-6: LED8.DOUT (DO), LED9.DIN (DI)
6-7: LED9.DOUT (DO), LED10.DIN (DI)
7-8: LED10.DOUT (DO), LED11.DIN (DI)
8-9: LED12.DOUT (DO), LED13.DIN (DI)
9-10: LED14.DOUT (DO), LED15.DIN (DI)
10-11: LED15.DOUT (DO), LED16.DIN (DI)
11-12: LED16.DOUT (DO), LED17.DIN (DI)
12-13: LED18.DOUT (DO), LED19.DIN (DI)
13-14: LED20.DOUT (DO), LED21.DIN (DI)
14-15: LED21.DOUT (DO), LED22.DIN (DI)
15-16: LED22.DOUT (DO), LED23.DIN (DI)
unnamed: LED1.DOUT (DO), LED2.DIN (DI)
unnamed: DIN.1, LED1.DIN (DI)
unnamed: LED5.DOUT (DO), LED6.DIN (DI)
unnamed: LED7.DOUT (DO), LED8.DIN (DI)
unnamed: DOUT.1, LED24.DOUT (DO)
unnamed: LED17.DOUT (DO), LED18.DIN (DI)
unnamed: LED11.DOUT (DO), LED12.DIN (DI)
unnamed: LED13.DOUT (DO), LED14.DIN (DI)
unnamed: LED23.DOUT (DO), LED24.DIN (DI)
unnamed: LED19.DOUT (DO), LED20.DIN (DI)
VDD: +5V.1, +5V..1, C1.1, C2.1, C3.1, C4.1, C5.1, C6.2, C7.2, C8.2, C9.2, C10.2, C11.1, C12.1, C13.1, C14.1, C15.1, C16.2, C17.2, C18.2, C19.2, C20.2, LED1.VDD, LED2.VDD, LED3.VDD, LED4.VDD, LED5.VDD, LED6.VDD, LED7.VDD, LED8.VDD, LED9.VDD, LED10.VDD, LED11.VDD, LED12.VDD, LED13.VDD, LED14.VDD, LED15.VDD, LED16.VDD, LED17.VDD, LED18.VDD, LED19.VDD, LED20.VDD, LED21.VDD, LED22.VDD, LED23.VDD, LED24.VDD
VSS: C1.2, C2.2, C3.2, C4.2, C5.2, C6.1, C7.1, C8.1, C9.1, C10.1, C11.2, C12.2, C13.2, C14.2, C15.2, C16.1, C17.1, C18.1, C19.1, C20.1, GND.1, LED1.VSS (GND), LED2.VSS (GND), LED3.VSS (GND), LED4.VSS (GND), LED5.VSS (GND), LED6.VSS (GND), LED7.VSS (GND), LED8.VSS (GND), LED9.VSS (GND), LED10.VSS (GND), LED11.VSS (GND), LED12.VSS (GND), LED13.VSS (GND), LED14.VSS (GND), LED15.VSS (GND), LED16.VSS (GND), LED17.VSS (GND), LED18.VSS (GND), LED19.VSS (GND), LED20.VSS (GND), LED21.VSS (GND), LED22.VSS (GND), LED23.VSS (GND), LED24.VSS (GND)

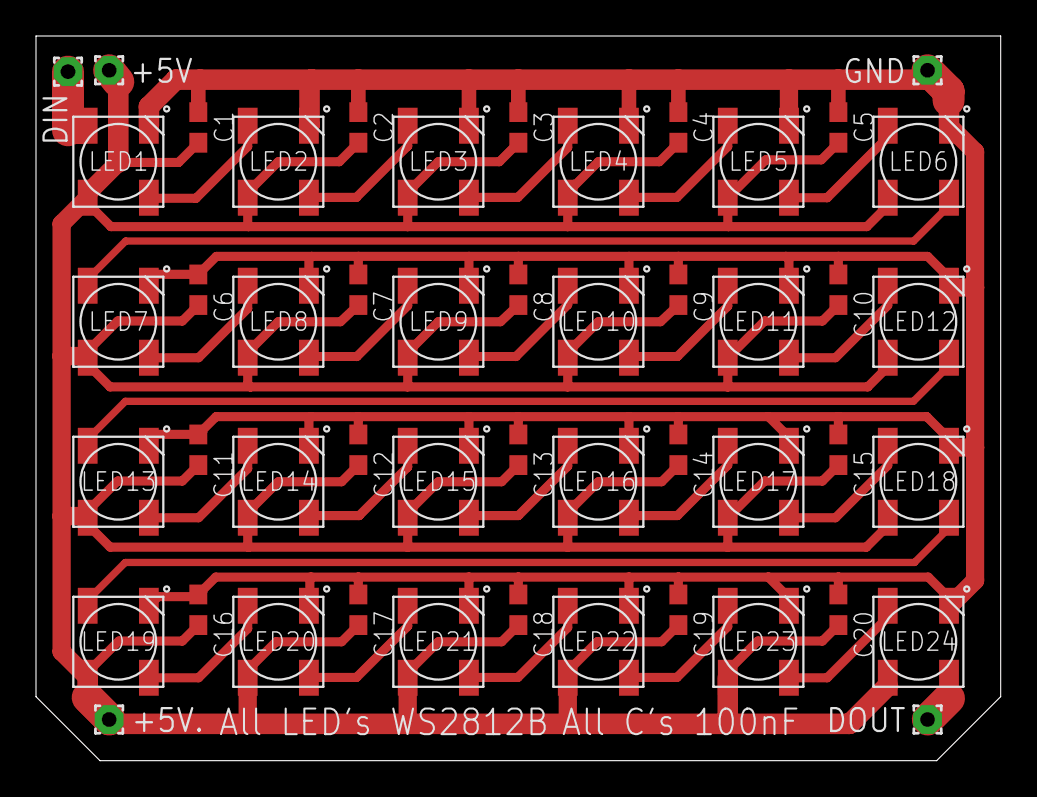
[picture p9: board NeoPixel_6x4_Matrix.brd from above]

Board: 2 copper layers, 53.6 x 40.3 mm, 49 parts (0 on the bottom side), 27 nets.

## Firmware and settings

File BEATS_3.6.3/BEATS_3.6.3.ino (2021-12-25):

/*
  BEATS - MIDI Beat Counter Version 1.3
  Based on Teensy 3.6 or higher, runs from 48 Mhz 

  MIDI -> show MIDI note and pressure value above MIDI

  Reset EEprom: press Shift, left and right encoder at the same time, power up and hold for at least 2 sec.
*/

// https://platformio.org/lib/show/70/Audio
// https://gammon.com.au/forum/?id=14175
// https://github.com/Circuito-io/Basic-Circuits/tree/master/ledbar_mic
// https://www.tweaking4all.com/hardware/arduino/adruino-led-strip-effects/

/*
https://github.com/bblanchon/ArduinoTrace
https://www.codeproject.com/Articles/1037057/Debugger-for-Arduino
http://visualmicro.blogspot.com/
https://mcuoneclipse.com/2014/08/09/hacking-the-teensy-v3-1-for-swd-debugging/
https://docs.platformio.org/en/latest/plus/debugging.html#piodebug
*/

// which version?
#define MBC_361 // Teensy 3.6 version with two shift buttons included in the keypad matrix
//#define MBC_36 // Teensy 3.6 version with one shift button


// which display? TFT or OLED could be used with LED in parallel
//#define Adafruit_TFT128   // https://www.adafruit.com/products/2088
#define Adafruit_TFT240   // https://www.aafruit.com/product/3787 or https://www.berrybase.de/neu/1.3-240x240-ips-hd-lcd-display-modul-spi-interface
//#define Adafruit_OLED  // runs only with cpu speed overclock https://www.adafruit.com/products/1431 
//or https://www.berrybase.de/neu/1.5-128x128-oled-display-modul-rgb-spi-interface?c=123
//#define LED_8x8matrix // Adafruit i2c LED 8x8 matrix display


#if defined(LED_8x8matrix)
//  #define LED_8x8_info // information output on LED 8x8 matrix
  #include "Adafruit_LEDBackpack.h" // LED_8x8; modified for use i2c_t3
//  Adafruit_BicolorMatrix matrix = Adafruit_BicolorMatrix(); // with I2C
  Adafruit_8x8matrix matrix = Adafruit_8x8matrix(); // with I2C
#endif


// which serial port for MIDI-DIN? No definition switch off MIDI-DIN
#define MIDI_SERIAL_2
//#define MIDI_SERIAL_3

#include "HardwareSerial.h"

#include <Encoder.h>
//#define ENCODER_DO_NOT_USE_INTERRUPTS
#define ENCODER_OPTIMIZE_INTERRUPTS

// keypad and encoder buttons
#include <Keypad.h>
#if defined(MBC_361)
  Encoder rightEnc(28, 24); // use pin 28 & 29
  long rightPos  = -999;
  Encoder leftEnc(31, 32); // use pin 31 & 32
  long leftPos  = -999;
  #define rightENC_BTN 27
  #define rightENC_RED 35
  #define rightENC_GREEN 36
  #define rightENC_BLUE 29
  #define leftENC_BTN 39
  #define leftENC_RED 38
  #define leftENC_GREEN 37
  #define leftENC_BLUE 30
  #define iLED 29     // LED pin on Teensy board; 11 for Teensy2.0; 13 for Teensy3.1/2/6 (30 = enc_bl)
  const byte ROWS = 6; // 6x5 keys 
  const byte COLS = 5; // cols and rows exchanged because of diodes direction
  char keys[ROWS][COLS] = {
    { 'A', 'B', 'C', 'D', 'x' },
    { 13,   9,   5,   1,  'S' },
    { 14,  10,   6,   2,  's' },
    { 15,  11,   7,   3,  'x' },
    { 16,  12,   8,   4,  'x' },
    { 'a', 'b', 'c', 'd', 'x' }  
  };
  byte colPins[COLS] = { 14, 15, 16, 17, 12 }; //connect to the row pinouts of the keypad
  byte rowPins[ROWS] = { 20, 33, 34, 25, 26, 21 }; //connect to the column pinouts of the keypad
#elif defined(MBC_36)
  Encoder rightEnc(28, 29); // use pin 28 & 29
  long rightPos  = -999;
  Encoder leftEnc(31, 32); // use pin 31 & 32
  long leftPos  = -999;
  #define Shift_BTN 12
  #define rightENC_BTN 27
  #define rightENC_RED 24
  #define rightENC_GREEN 25
  #define rightENC_BLUE 26
  #define leftENC_BTN 39
  #define leftENC_RED 38
  #define leftENC_GREEN 37
  #define leftENC_BLUE 30
  #define iLED 26     // LED pin on Teensy board; 11 for Teensy2.0; 13 for Teensy3.1/2/6 (30 = enc_bl)
  const byte ROWS = 4; // 6x4 keys
  const byte COLS = 6;
  char keys[ROWS][COLS] = {
    { 'A', 13, 14, 15, 16, 'a' },
    { 'B',  9, 10, 11, 12, 'b' },
    { 'C',  5,  6,  7,  8, 'c' },
    { 'D',  1,  2,  3,  4, 'd' }
  //{  '','S','s', '', '',  '' }   
  };
  byte rowPins[ROWS] = { 14, 15, 16, 17 }; //connect to the row pinouts of the keypad
  byte colPins[COLS] = { 20, 33, 34, 35, 36, 21 }; //connect to the column pinouts of the keypad
#endif
Keypad keypad = Keypad( makeKeymap(keys), rowPins, colPins, ROWS, COLS );


unsigned long loopCount;
unsigned long startTime;
unsigned long ticker;
unsigned long bpm_ms = 1800 ; // set to 120 bpm
unsigned long bpm = 120 ; // set to 120 bpm
String kbd_msg = "";
byte keypad_shift = 0;
bool shift = false;
byte key_ana[ROWS*COLS]; // analog key


#include <MIDI.h>
MIDI_CREATE_DEFAULT_INSTANCE();

#include <EEPROM.h>
//#include <SD.h>
#include <SPI.h>
#include "SdFat.h" // https://github.com/greiman/SdFat
#include <TimerThree.h>


byte DMXbuffer[516]; // Minimum size = number of channels + 1. Add more channels if the last light flickers. This seems reliable: size = number of channels + 4.
// Send at least 24 channels (25 bytes) to keep time between breaks above 1.2 milliseconds. Some DMX hardware may not be able to handle faster refresh times.
//int serial1TXbuffersizeminus1;

// TeensyDMX needs to be included before ST7735_t3.h https://github.com/ssilverman/TeensyDMX
#include <TeensyDMX.h>
namespace teensydmx = ::qindesign::teensydmx;
constexpr uint8_t kTXPin = 2; // Pin for enabling or disabling the transmitter
teensydmx::Sender dmxTx{Serial1}; // Create the DMX sender on Serial1


#include "Adafruit_GFX.h" // graphic library
float p = 3.1415926;

// TFT Adafruit_ST77xx   FEDCBA9876543210    #####################################
// Color definitions     RRRRRggggggBBBBB
#define TFT_Black 0x0000
#define TFT_Gray       0b0111101111101111
#define TFT_LightGray  0b1011110111110111
#define TFT_DarkGray   0b0001100011100011
#define TFT_DarkerGray 0b0000100001100001
#define TFT_Blue 0x001F
#define TFT_DarkBlue   0b0000000000010111
#define TFT_Red 0xF800
#define TFT_DarkRed    0b1001100000000000
#define TFT_Orange 0xFA00
#define TFT_Green 0x07E0
#define TFT_DarkGreen   0b0000010000000000
#define TFT_DarkerGreen 0b0000000011100000
#define TFT_Cyan 0x07FF
#define TFT_LightCyan 0b0000011110011100
//                      RRRRRggggggBBBBB
#define TFT_MENU_1UP  0b1111111111111111
#define TFT_MENU_2UP  0b0000011000011000
#define TFT_Magenta 0xF81F
#define TFT_Yellow 0xFFE0
#define TFT_White 0xFFFF
#define TFT_MenuBack 0x0004

#define TFT_SCLK 13  // SCLK can also use pin 14
//#define TFT_MISO 12  // used as key row5
#define TFT_MOSI 11  // MOSI can also use pin 7
#define TFT_CS   6   // CS & DC can use pins 2, 6, 9, 10, 15, 20, 21, 22, 23
#define TFT_RST  5   // RST can use any pin or set to -1 and connect to RESET pin
#define TFT_DC   4   // but certain pairs must NOT be used: 2+10, 6+9, 20+23, 21+22

// Adafruit TFT displays
#if defined(Adafruit_TFT128)
  // This SPI Teensy3 native optimized version requires specific pins
  #if defined(__SAM3X8E__)
    #undef __FlashStringHelper::F(string_literal)
    #define F(string_literal) string_literal
  #endif
  #include <ST7735_t3.h> // TFT Hardware-specific library
  ST7735_t3 tft = ST7735_t3(TFT_CS, TFT_DC, TFT_MOSI, TFT_SCLK, TFT_RST);
#elif defined(Adafruit_TFT240)
  #include <ST7789_t3.h> // Hardware-specific library
  #include <ST7735_t3_font_Arial.h>
  #include <ST7735_t3_font_ArialBold.h>
  ST7789_t3 tft = ST7789_t3(TFT_CS, TFT_DC, TFT_MOSI, TFT_SCLK, TFT_RST);
#elif defined(Adafruit_OLED) // Adafruit OLED display
  #include <Adafruit_SSD1351.h> // OLED Hardware-specific library
//  Adafruit_SSD1351 tft = Adafruit_SSD1351(TFT_CS, TFT_DC, TFT_MOSI, TFT_SCLK, TFT_RST);
  Adafruit_SSD1351 tft = Adafruit_SSD1351(TFT_CS, TFT_DC, TFT_RST);
#endif

// https://learn.adafruit.com/creating-custom-symbol-font-for-adafruit-gfx-library/overview
// getTextBounds() Adafruit_GFX_Button, GFXcanvas1, GFXcanvas8, GFXcanvas16, GFXfont
// tft.getTextBounds(string, x, y, &x1, &y1, &w, &h);

//#include <Fonts/FreeMonoBoldOblique24pt7b.h>
//#include <Fonts/FreeMono9pt7b.h>
//#include <Fonts/FreeMono12pt7b.h>
//#include <Fonts/FreeMono24pt7b.h>
//#include <Fonts/FreeSerif9pt7b.h>

//#include <Fonts/FreeMono18pt7b.h>
//#include <Fonts/FreeMonoBold18pt7b.h>

#include <Fonts/FreeSans9pt7b.h>
#include <Fonts/FreeSans12pt7b.h>
#include <Fonts/FreeSans18pt7b.h>
#include <Fonts/FreeSans24pt7b.h>
#include <Fonts/FreeSansBold9pt7b.h>
#include <Fonts/FreeSansBold12pt7b.h>
#include <Fonts/FreeSansBold18pt7b.h>
#include <Fonts/FreeSansBold24pt7b.h>


#include <Adafruit_NeoPixel.h>
#define NUMPIXELS 104 // How many NeoPixels? 16 + 24 + 64
#define PIN 23 // NeoPixel data port
Adafruit_NeoPixel pixels = Adafruit_NeoPixel(NUMPIXELS, PIN, NEO_GRB + NEO_KHZ800);


//#include <RGBLed.h>
//RGBLed LE_led( 38, 37, 30, COMMON_ANODE); // left encoder LED
//RGBLed RE_led( 24, 25, 26, COMMON_ANODE); // right encoder LED
//LE_led.setColor(255, 0, 0);
//LE_led.flash(255, 0, 0, 250, 100); // Interval 250/100ms


unsigned long current_ms_left = millis();
unsigned long current_ms_right = millis();
unsigned long previous_ms_left = 0; 
unsigned long previous_ms_right = 0; 

// Menu for TFT
#define leftTFT_MenuLines 6
const char* leftTFT_Menu[] = {
  "Back Color", // -2
  "Text Font", // -1
  "Count Lengt",
  "MIDI Channel",
  "MIDI Address",
  "Text Color",
  "Back Color",
  "Text Font",
  "Count Lengt", // +1
  "MIDI Channel"  // +2
};

const char* leftTFT_LongMenu[] = {
  "Beat Count Length",
  "MIDI Channel",
  "MIDI Base Address",
  "TFT Text Color",
  "TFT Back Color",
  "TFT Text Font"
};

#define rightTFT_MenuLines 6
const char* rightTFT_Menu[] = {
  "Display 64", // -2
  "Neo Bright", // -1
  "DMX Address", // Scan View
  "DMX Units",
  "COB Pattern",
  "Brightness",
  "Display 64",
  "Neo Bright",
  "DMX Address", // +1
  "DMX Units"  // +2
};

const char* rightTFT_LongMenu[] = {
  "DMX Base Address",
  "DMX Units Selection",
  "DMX COB Pattern",
  "DMX Brightness",
  "HAT for 64 Pattern",
  "Neopixel Brightness"
};

const byte DMXBaseEE = 0; // DMX base address
const byte DMXUnitsEE = 1; // DMX units selection BSxCCSPP = Beats/Bars, Scanner Prog, xx, COB, Scanner, Pixbar
const byte DMXPatternEE = 2; // DMX COB pattern
const byte DMXBrightEE = 3; // DMX brightness for Pixbar and COB
const byte HATPatternEE = 4; // Select which HAT to use, Waveshare or Unicorn
const byte NeoPixelBrightEE = 5; // Neopixel brightness
const byte rightEncoderStartEE = 9; // Encoder start point, not used for menu

// section 10 - 19 used for secondary encoder, needs to be at same single position as main encoder (bright 3 = back 13, count 20 = start = 10 etc.)
const byte CountLenghtEE = 10; // beats-1, 256= 255, 128=127, 64=63, 32=31, 16=15
const byte DMXPixbarEE = 12; // DMX pattern for Cameo COB 8x LED
const byte DMXBackBrightEE = 13; // DMX backlight

const byte BeatStartEE = 20; // Beat start
const byte MIDIChannelEE = 21; // MIDI Channel
const byte MIDIBaseAdrEE = 22; // MIDI Base Address
const byte LCDTextColorEE = 23; // LCD text color            FEDCBA9876543210 -> 76543210  LCD_Red, LCD_Green, LCD_Blue, LCD_Bright
const byte LCDBackColorEE = 24; // LCD background color     RRRRRggggggBBBBB -> hhRRggBB    
const byte LCDTextFontEE = 25; // LCD text font
const byte leftEncoderStartEE = 29; // Encoder start point, not used for menu

const word FixtureBaseEE = 1024; // scanner fixture base address 

byte leftEncMIDI_A = 0;
byte leftEncMIDI_B = 0;
byte leftEncMIDI_C = 0;
byte rightEncMIDI_D = 0;
byte rightEncMIDI_E = 0;
byte rightEncMIDI_F = 0;
byte leftEncRED = 0;
byte leftEncBlue = 0;
byte rightEncGreen = 0;
byte rightEncBright = 0;

byte DMXBase = EEPROM.read(DMXBaseEE);
byte DMXUnits = EEPROM.read(DMXUnitsEE);
byte DMXPattern = EEPROM.read(DMXPatternEE);
byte DMXBright = EEPROM.read(DMXBrightEE);
byte HATPattern = EEPROM.read(HATPatternEE);
byte NeoPixelBright = EEPROM.read(NeoPixelBrightEE);
byte rightEncoderStart = EEPROM.read(rightEncoderStartEE);

byte CountLenght = EEPROM.read(CountLenghtEE);
byte DMXPixbar = EEPROM.read(DMXPixbarEE);
byte DMXBackBright = EEPROM.read(DMXBackBrightEE);

byte BeatStart = EEPROM.read(BeatStartEE);
byte MIDIChannel = EEPROM.read(MIDIChannelEE); // <- Beat/Bar bit7 set here, upper nipple unused
byte MIDIBaseAdr = EEPROM.read(MIDIBaseAdrEE);
byte LCDTextColor = EEPROM.read(LCDTextColorEE);
byte LCDBackColor = EEPROM.read(LCDBackColorEE);
byte LCDTextFont = EEPROM.read(LCDTextFontEE)-1;
byte leftEncoderStart = EEPROM.read(leftEncoderStartEE);

// read first scanner values
byte ScanPan = EEPROM.read(FixtureBaseEE);
byte ScanTilt = EEPROM.read(FixtureBaseEE+1);
byte ScanColor = EEPROM.read(FixtureBaseEE+2);
byte ScanStrobe = EEPROM.read(FixtureBaseEE+3);
byte ScanGobo = EEPROM.read(FixtureBaseEE+4);
byte ScanRotate = EEPROM.read(FixtureBaseEE+5);
byte ScanPrisma = EEPROM.read(FixtureBaseEE+6);
byte ScanFocus = EEPROM.read(FixtureBaseEE+7);

//byte ScanBeats = 0;
//byte ScanFree = 0;

byte ScanMoveMode = 0;
byte ScanMoveDir = 0;

byte ScanMotion = 0;
byte ScanSpeed = 0;
byte ScanSpdMove = 0b01000000; // 7.6.5. = move (2 = move circle right), < 10 speed 
byte preScanSpdMove = 0;
byte ScanRun = 0;
byte ScanBPM = 0;

byte ScanSelected = 0;

byte leftLCDView = 0;
byte rightLCDView = 0;
byte MenuDepth = 0;
byte UnitsView = 0;
bool leftEncPressed = false;
bool rightEncPressed = false;

bool ProgMode = false;

byte leftLastEncoder = 1;
byte rightLastEncoder = 1;
byte KEYS = 0; 
byte DMX_LED = 0;
byte DMX_BG = 0;
byte COLOR = 0;

byte FSR = 0;
byte FSR_low = 0;
byte FSR_read = 0;

byte Counter = 0; // MIDI Beat Clock (1-24)
byte Count_Beats = (BeatStart & 0b00000011) ;
byte Count_8x8 = BeatStart;
byte Count_DMX = BeatStart;
byte NeoPixelFastCounter = 0;
byte RED = 0;
byte GREEN = 0;
byte BLUE = 0;
long RGB = 0;
long leftnewPos = 0;
long rightnewPos = 0;
String left_str = "";
String right_str = "";
byte left_half_bound = 0;
byte right_half_bound = 0;
int16_t txtX, txtY;
uint16_t txtW, txtH;

byte CAMEO_BASE_ADR = 0 ;
byte SCANNER_BASE_ADR = 0 ;
byte COB_BASE_ADR = 0 ;

const byte SPP = 242; // Song Position Pointer
const byte CLOCK = 248;
const byte START = 250;
const byte CONTINUE = 251;
const byte STOP = 252;
bool RUN = false; // used to identify song running or stopped

byte incomingByte;
byte miditype = 0;
byte usbMIDIdata1 = 0;
byte usbMIDIdata2 = 0;
uint32_t songPositionPointer = 0;
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
void loop() {
#if defined(MBC_36)
  if (digitalRead(Shift_BTN) == LOW) { shift = true; } else { shift = false; }
#endif

// debug
//  viewStatus(UnitsView, ProgMode, shift, leftEncPressed, leftLCDView, leftnewPos, rightEncPressed, rightLCDView, rightnewPos);

/*
// use the following 4 lines to kick the dog
noInterrupts();
WDOG_REFRESH = 0xA602;
WDOG_REFRESH = 0xB480;
interrupts()
// if you don't refresh the watchdog timer before it runs out, the system will be rebooted
*/
  
  CAMEO_BASE_ADR = DMXBase;
  SCANNER_BASE_ADR = DMXBase + (DMXUnits & 0b00000011) * 30;
  COB_BASE_ADR = DMXBase + (DMXUnits & 0b00000011) * 30 + ((DMXUnits & 0b00000100) >> 2) * 64 ;
  
  if (RUN==false) bpm_ms = millis();

/*  
  if ((millis()-ticker) > 100) { // update every 100ms

    ticker = millis();
  }
*/

//  Serial.print(" Mic: ");
//  Serial.println(analogRead(A11));

  loopCount++;

  if ( (millis()-startTime) > 50 && keypad.key[0].kstate > 0) {
    if(FSR_low > 0) {
      FSR = analogRead(A8) - FSR_low ;
      if(FSR > 127) { FSR = 127; }

      Serial.print(" FSR: ");
      Serial.print(FSR);
      Serial.print("   FSR_low: ");
      Serial.print(FSR_low);
      Serial.print("         Average loops per second = ");
      Serial.println(loopCount/5);

      usbMIDI.sendAfterTouch(FSR, MIDIChannel & 0b00001111); // Send aftertouch (pressure, channel)
//      MIDI.sendAfterTouch(FSR, MIDIChannel & 0b00001111); // Send aftertouch (pressure, channel)
    }
    startTime = millis();
    loopCount = 0;
  }
  if(keypad.key[0].kstate == 0) { FSR_low=0; FSR=0; }

  #include "Keys.h" // Keypad
  #include "EncLeft.h" // Encoder
  #include "EncRight.h" // Encoder

  // DMX ################################################################################
  #include "Cameo.h" // Cameo Pixbar 650
  #include "COB_4x4x4.h" // Eurolight LED PMC-16x30W, 4x4 COB LED 16x30W
  dmxTx.set(0, DMXbuffer, 512);
/*
  for (int i = 0; i < 64; i++) { 
    Serial.print(DMXbuffer[i],HEX);
    if(DMXbuffer[i] < 15 ) Serial.print(" ");
    Serial.print(" ");
  }
  Serial.println();
*/
  /// DMX ################################################################################

  if (usbMIDI.read()) // USB MIDI receive
  {
    miditype = usbMIDI.getType();
    usbMIDIdata1 = usbMIDI.getData1();
    usbMIDIdata2 = usbMIDI.getData2();
/*
    Serial.print("usbMIDItype:");
    Serial.print(miditype);
    Serial.print(" 1:");
    Serial.print(usbMIDIdata1);
    Serial.print(" 2:");
    Serial.print(usbMIDIdata2);
    Serial.print(" SPP:");
    Serial.println(songPositionPointer);
*/    
    if (miditype == SPP) { 
      songPositionPointer = usbMIDIdata2 * 128 + usbMIDIdata1;
      Count_Beats = (songPositionPointer & 0b00000011) ;
      Count_DMX = songPositionPointer / 4 + BeatStart ;
      if (bitRead(MIDIChannel,7)==0) { Count_8x8 = Count_DMX; }
      else { Count_8x8 = songPositionPointer / 16 + BeatStart; }
      SPPupdate();
      if ( MenuDepth == 0  && songPositionPointer % 4 == 0 && RUN == true && UnitsView != 1 ) { TFT_Draw_Count(); }
      else if ( MenuDepth == 0 && UnitsView != 1 ) { TFT_Draw_Count(); }
      for (int i = 0; i < 16; i++) pixels.setPixelColor(i, pixels.Color(0, 0, 0)); // clear neopixel ring  
      ClearCounter();
      NeoPixelFastCounter = songPositionPointer * 6 % 96 ;
      Counter = songPositionPointer * 6  % 24 -1 ;
      ClockCounter();
    }
  }


#if defined(MIDI_SERIAL_2)
  if (Serial2.available() > 0) { 
    incomingByte = Serial2.read();
    CheckClock(); }
#endif

#if defined(MIDI_SERIAL_3)
  if (Serial3.available() > 0) {
    incomingByte = Serial3.read();
    CheckClock(); }
#endif

//    Serial.print("MIDI-DIN incoming Byte: ");
//    Serial.println(incomingByte, DEC);


#if defined(LED_8x8matrix) // LED matrix 8x8 ############################################

// number counting
  if (keypad.key[0].kstate == 0) { // no button pressed
    matrix.clear();
    if ((Count_8x8 % 32) < 16) {
      matrix.drawBitmap(0, 0, num_ + ((Count_8x8 % (CountLenght + 1)) + 1) * 8, 8, 8, LED_GREEN);
    }
    else if ((Count_8x8 % 32) < 24) {
      matrix.drawBitmap(0, 0, num_ + ((Count_8x8 % (CountLenght + 1)) + 1) * 8, 8, 8, LED_YELLOW);
    }
    else {
      matrix.drawBitmap(0, 0, num_ + ((Count_8x8 % (CountLenght + 1)) + 1) * 8, 8, 8, LED_RED);
    }
  }

  // bar counting
  matrix.drawBitmap(0, 6, BAR_8 + ((Count_8x8 >> 2) % 8), 8, 1, LED_YELLOW);
  matrix.drawBitmap(0, 6, BAR_2 + ((Count_8x8 >> 4) % 2), 8, 1, LED_RED);

  // blink LED
  if ((Count_8x8 % 32) > 23 && Counter > 11) matrix.drawBitmap(0, 6, BAR_8 + 7, 8, 1, LED_OFF);

  // every beat
  matrix.drawBitmap(0, 7, BAR_8 + 7, 8, 1, LED_OFF); // clear last row
  matrix.drawBitmap(0, 7, BAR_4 + (Count_8x8 % 4), 8, 1, LED_GREEN);

  matrix.writeDisplay();
 
#endif /// LED matrix 8x8 ###############################################################

}
/// LLLLLLLLLLLLLLLLLLLLLLLLLLLLLLLLLLLLLLLLLLLLLLLLLLLLLLLLLLLLLLLLLLLLLLLLLLLLLLLLLLLLLLLLLLLLLLLLLLLLLL


void RealTimeSystem(byte realtimebyte) {
  incomingByte = realtimebyte;          // <<<<<<<<<<<<<<<<<<<<<<<<<<<<<<<<<<<<<<<<<<<<<<
//    Serial.print("MIDI-USB incoming Byte: ");
//    Serial.println(incomingByte, DEC);
  CheckClock();
}

/*
void songPositionPointer(uint16_t songPosition) {
  Serial.print ("Song position: ");
  Serial.print (songPosition);
  Serial.print ("   Counter: ");
  Serial.println (Counter);

  Count_8x8 = songPosition/4 ;
  Count_DMX = songPosition/4 ;
  NeoPixelFastCounter = 0;
  incomingByte = SPP;
//  CheckClock();
}
*/

void CheckClock() {

  switch (incomingByte) {

    case CLOCK:
      ClockCounter();
//        Serial.print("Clock: ");
//        Serial.println(incomingByte, DEC);
        RUN = true;
      break;

    case START:
//      ClearCounter();
//      Serial.print("Start: ");
//      Serial.println(incomingByte, DEC);
//      if (keypad.key[0].kstate == 0 && digitalRead(rightENC_GREEN) == HIGH) { // no button pressed and green encoder LED off
//        TFT_Counter(); // write 1st beat to TFT
//      } 
        RUN = true;
      break;

    case CONTINUE:
//      ClearCounter();
//      Serial.print("Continue: ");
//      Serial.println(incomingByte, DEC);
//      if (keypad.key[0].kstate == 0 && digitalRead(rightENC_GREEN) == HIGH) { // no button pressed and green encoder LED off
//        TFT_Counter(); // write 1st beat to TFT
//      } 
        RUN = true;
      break;

    case STOP:
//      Serial.print("Stop: ");
//      Serial.println(incomingByte, DEC);
      RUN = false;
      break;

    case SPP:
      break;

    default:
      break;
  }
}


void ClockCounter() {

  Counter++;
  switch(Counter) {
    case 4:
      digitalWrite(iLED, HIGH);
      break;
    case 6:
      songPositionPointer++;
      if (RUN==true) { SPPupdate(); }
      break;
    case 12:
      songPositionPointer++;
      if (RUN==true) { SPPupdate(); }
      break;
    case 18:
      songPositionPointer++;
      if (RUN==true) { SPPupdate(); }
      break;
    case 20:
      Count_DMX++;  // shifts DMX out
      if(bitRead(MIDIChannel, 7)==0) { Count_8x8++; }
      else { Count_Beats++; if(Count_Beats > 3) { Count_Beats=0; Count_8x8++; }}    
      break;
    case 24:
      Counter = 0;
      songPositionPointer++;
      if (RUN==true) { SPPupdate(); }
      digitalWrite(iLED, LOW);
      break;
  }

  NeoPixelFastCounter++;
  if (NeoPixelFastCounter == 96) {
    NeoPixelFastCounter = 0;
    if (RUN == true && MenuDepth == 0) {
      tft.setFont();
      tft.setTextSize(_ts);
      tft.setTextColor(TFT_LightGray, TFT_Black);
      tft.setCursor(_tw/2+_ts*20, _ty+_ts*2);
      bpm = (bpm + 78692*pow(millis()-bpm_ms,-0.8662)+1) / 2 ;
//      tft.print(bpm);
      tft.setTextColor(TFT_Gray, TFT_Black);
      tft.setCursor(_tw/2+_ts*40, _ty+_ts*2);
//      tft.print("bpm");
    }
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

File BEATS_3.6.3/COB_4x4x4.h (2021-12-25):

// COB 4x4x4 direct ###################################################################
// 48 channel mode 4x4 RGB
// COB_BASE_ADR = DMXBase + (DMXUnits & 0b00000011) * 30 + ((DMXUnits & 0b00000100) >> 2) * 64 ;

if(((DMXUnits & 0b00011000) >> 3) > 0) {
  
  if (DMXPattern == 0 || DMXPattern == 4 || DMXPattern == 5 || DMXPattern == 6 || DMXPattern == 10 || DMXPattern == 11 || DMXPattern == 12 || DMXPattern >= 14) 
  {
    for ( COLOR = 0; COLOR < 3; COLOR++) {

      // background color
      if (COLOR == 2 && (Count_DMX % 32) < 16) {
        DMX_BG = DMXBackBright;  // 1-16
      }
      else if (COLOR == 2 && (Count_DMX % 32) > 15 && (Count_DMX % 32) < 24) {
        DMX_BG = DMXBackBright;  // 17-24
      }
      else if ((COLOR == 1 || COLOR == 2) && (Count_DMX % 32) > 23 && (Count_DMX % 32) < 32) {
        DMX_BG = DMXBackBright;  // 25-32
      }
      else {
        DMX_BG = 0;
      }

      // number counting
      if (COLOR == 1 && (Count_DMX % 32) < 16) {
        DMX_LED = DMXBright;  // 1-16
      }
      else if ((COLOR == 0 || COLOR == 1) && (Count_DMX % 32) > 15 && (Count_DMX % 32) < 24) {
        DMX_LED = DMXBright;  // 17-24
      }
      else if (COLOR == 0 && (Count_DMX % 32) > 23 && (Count_DMX % 32) < 32) {
        DMX_LED = DMXBright;  // 25-32
      }
      else {
        DMX_LED = 0;
      }
      
      for (int j = 0; j < 4; j++) {
        for (int i = 0; i < 4; i++) {
          if (bitRead(pgm_read_byte_near(num_ + ((Count_DMX % (CountLenght + 1)) + 1) * 8 + j), (7 - i)) == 1 ) {
            DMXset((COB_BASE_ADR) + (i + (j * 4)) * 3 + COLOR, DMX_LED);
          }
          else {
            DMXset((COB_BASE_ADR) + (i + (j * 4)) * 3 + COLOR, DMX_BG);
          }

          if (bitRead(pgm_read_byte_near(num_ + ((Count_DMX % (CountLenght + 1)) + 1) * 8 + j), (3 - i)) == 1 ) {
            DMXset((COB_BASE_ADR) + (i + (j * 4)) * 3 + COLOR + 48, DMX_LED);
          }
          else {
            DMXset((COB_BASE_ADR) + (i + (j * 4)) * 3 + COLOR + 48, DMX_BG);
          }
        }
      }
      for (int j = 0; j < 2; j++) {
        for (int i = 0; i < 4; i++) {
          if (bitRead(pgm_read_byte_near(num_ + ((Count_DMX % (CountLenght + 1)) + 1) * 8 + j + 4), (7 - i)) == 1 ) {
            DMXset((COB_BASE_ADR) + (i + (j * 4)) * 3 + COLOR + 96, DMX_LED);
          }
          else {
            DMXset((COB_BASE_ADR) + (i + (j * 4)) * 3 + COLOR + 96, DMX_BG);
          }

          if (bitRead(pgm_read_byte_near(num_ + ((Count_DMX % (CountLenght + 1)) + 1) * 8 + j + 4), (3 - i)) == 1 ) {
            DMXset((COB_BASE_ADR) + (i + (j * 4)) * 3 + COLOR + 144, DMX_LED);
          }
          else {
            DMXset((COB_BASE_ADR) + (i + (j * 4)) * 3 + COLOR + 144, DMX_BG);
          }
        }
      }
    }

    // bar counting
    DMX_LED = DMXBright;
    if (Counter > 11 && (Count_DMX % 32) > 23) {
      DMX_LED = 0; // flashing
    }

    for (int i = 0; i < 4; i++) {
      COLOR = 0; // red
      DMXset((COB_BASE_ADR) + (11 - i) * 3 + COLOR + 96, bitRead(pgm_read_byte_near(BAR_8 + (Count_DMX >> 2) % 8 ), i + 4)*DMX_LED);
      DMXset((COB_BASE_ADR) + (11 - i) * 3 + COLOR + 144, bitRead(pgm_read_byte_near(BAR_8 + (Count_DMX >> 2) % 8 ), i)*DMX_LED);
      DMXset((COB_BASE_ADR) + (15 - i) * 3 + COLOR + 96, 0); // every beat
      DMXset((COB_BASE_ADR) + (15 - i) * 3 + COLOR + 144, 0); // every beat
      COLOR = 1; // green
      DMXset((COB_BASE_ADR) + (11 - i) * 3 + COLOR + 96, bitRead(pgm_read_byte_near(BAR_8 + (Count_DMX >> 2) % 8 ), i + 4)*DMX_LED);
      DMXset((COB_BASE_ADR) + (11 - i) * 3 + COLOR + 144, bitRead(pgm_read_byte_near(BAR_8 + (Count_DMX >> 2) % 8 ), i)*DMX_LED);
      DMXset((COB_BASE_ADR) + (15 - i) * 3 + COLOR + 96, bitRead(pgm_read_byte_near(BAR_4 + (Count_DMX % 4)), i + 4)*DMX_LED); // every beat
      DMXset((COB_BASE_ADR) + (15 - i) * 3 + COLOR + 144, bitRead(pgm_read_byte_near(BAR_4 + (Count_DMX % 4)), i)*DMX_LED); // every beat
      COLOR = 2; // blue
      DMXset((COB_BASE_ADR) + (11 - i) * 3 + COLOR + 96, 0);
      DMXset((COB_BASE_ADR) + (11 - i) * 3 + COLOR + 144, 0);
      DMXset((COB_BASE_ADR) + (15 - i) * 3 + COLOR + 96, bitRead(pgm_read_byte_near(BAR_4 + (Count_DMX % 4)), i + 4)*DMX_LED); // every beat
      DMXset((COB_BASE_ADR) + (15 - i) * 3 + COLOR + 144, bitRead(pgm_read_byte_near(BAR_4 + (Count_DMX % 4)), i)*DMX_LED); // every beat
    }
  }


  if (DMXPattern == 1 || DMXPattern == 4 || DMXPattern == 7 || DMXPattern == 9 || DMXPattern == 10 || DMXPattern == 12 || DMXPattern == 13 || DMXPattern == 14) 
  {
    for ( COLOR = 0; COLOR < 3; COLOR++) {

      // background color
      if (COLOR == 1 && (Count_DMX % 32) < 16) {
        DMX_BG = DMXBackBright;  // 1-16
      }
      else if (COLOR == 2 && (Count_DMX % 32) > 15 && (Count_DMX % 32) < 24) {
        DMX_BG = DMXBackBright;  // 17-24
      }
      else if ((COLOR == 0 || COLOR == 2) && (Count_DMX % 32) > 23 && (Count_DMX % 32) < 32) {
        DMX_BG = DMXBackBright;  // 25-32
      }
      else {
        DMX_BG = 0;
      }
      //      if ((COLOR==0 || COLOR==2) && (Count_DMX % 32 > 23) && (Count_DMX % 32 < 32)) { DMX_BG = (24-Counter)*DMXBackBright/24 ; } // flash last 4 beats

      // counting shp_256_
      if (COLOR == 0 && (Count_DMX % 5) == 0) {
        DMX_LED = (24 - Counter) * DMXBright / 24;
      }
      else if (COLOR == 0 && (Count_DMX % 5) == 3) {
        DMX_LED = (24 - Counter) * DMXBright / 24;
      }
      else if (COLOR == 0 && (Count_DMX % 5) == 5) {
        DMX_LED = (24 - Counter) * DMXBright / 24;
      }
      else if (COLOR == 1 && (Count_DMX % 5) == 1) {
        DMX_LED = (24 - Counter) * DMXBright / 24;
      }
      else if (COLOR == 1 && (Count_DMX % 5) == 3) {
        DMX_LED = (24 - Counter) * DMXBright / 24;
      }
      else if (COLOR == 1 && (Count_DMX % 5) == 4) {
        DMX_LED = (24 - Counter) * DMXBright / 24;
      }
      else if (COLOR == 2 && (Count_DMX % 5) == 2) {
        DMX_LED = (24 - Counter) * DMXBright / 24;
      }
      else if (COLOR == 2 && (Count_DMX % 5) == 4) {
        DMX_LED = (24 - Counter) * DMXBright / 24;
      }
      else if (COLOR == 2 && (Count_DMX % 5) == 5) {
        DMX_LED = (24 - Counter) * DMXBright / 24;
      }
      else {
        DMX_LED = 0;
      }

      for (int j = 0; j < 4; j++) {
        for (int i = 0; i < 4; i++) {
          if (bitRead(pgm_read_byte_near(shp_256_ + ((Count_DMX % (CountLenght + 1)) + 1) * 8 + j), (7 - i)) == 1 ) {
            DMXset((COB_BASE_ADR) + (i + (j * 4)) * 3 + COLOR, DMX_LED);
          }
          else {
            DMXset((COB_BASE_ADR) + (i + (j * 4)) * 3 + COLOR, DMX_BG);
          }
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

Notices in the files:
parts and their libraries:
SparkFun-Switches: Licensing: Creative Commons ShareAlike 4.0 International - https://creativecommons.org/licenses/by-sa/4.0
